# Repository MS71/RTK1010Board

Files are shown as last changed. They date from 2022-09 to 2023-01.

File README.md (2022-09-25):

# RTK1010Board
Arduino Compatible RTK1010 Board/PCB

! Design not finished yet !

Feature:

* Arduino compatibe form factor
* RTK1010 GPS receiver
* optional SMA connector for external antennas
* IPEX connector for onboard antennas
* optional LDO for LNA power supply
* optional ESP32-S2 for operating as base station
* optional power via USB
* optional backup battery
* optional BNO055 IMU

Use Cases:

A.) Minimum RTK-1010 receiver with arduino form factor. 
* just RTK-1010 to RX/TX arduino pin
* SMA or IPEX connected
* LNA power by rtk-1010
* optional backup bat for RTK-1010
* optional LNA LDO

B.) Minimum USB powered RTK base station with RTK-1010, ESP32-S2.  
* ESP32: RTK <=> TCP bridge
* powered by USB
* SMA or IPEX connected
* LNA power
* optional backup bat for RTK-1010
* optional LNA LDO

C.) Mowgli HEAD with RTK-1010, ESP32-S2 and BNO055 IMU (todo)
* ESP32: running microROS
* VCC, GND, UART interface to YF mainboard
* low power, sleep mode

[Build Manual](BuildManual.pdf)

[RTK 1010 datasheet](https://www.locosystech.com/Templates/att/RTK-1010_datasheet_v0.7.pdf)

[Schematic](RTK1010Board.pdf)


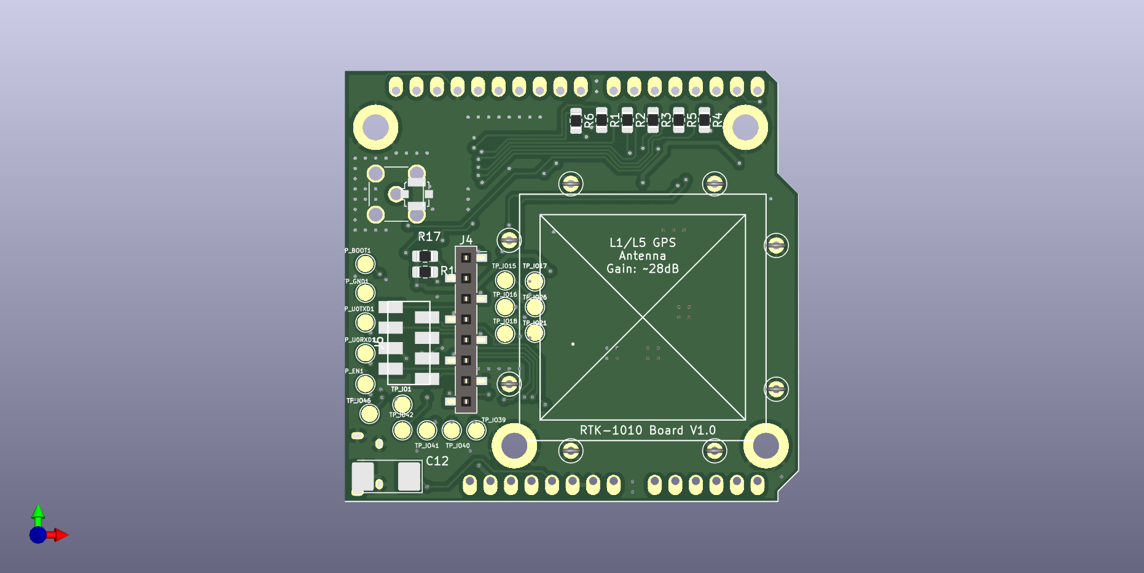
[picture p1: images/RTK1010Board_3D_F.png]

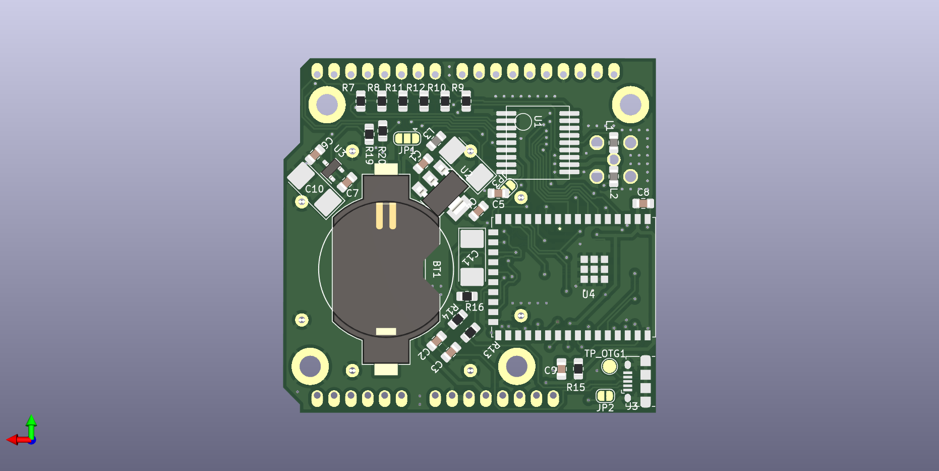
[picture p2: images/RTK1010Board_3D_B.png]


[iBOM](bom/ibom.html)

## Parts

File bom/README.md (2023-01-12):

# RTK1010-PCB-BOM

#### A) Minimum RTK-1010 receiver with arduino form factor

  - RTK-1010 <-> RX/TX arduino pins
  - SMA or IPEX connector
  - LNA power by RTK-1010
  - RTK-1010 backup battery
  - *(optional)* LNA LDO

#### B) Minimum RTK base station with RTK-1010 & ESP32-S2 powered by USB

  - ESP32: RTK <=> TCP bridge
  - powered by USB
  - SMA or IPEX connector
  - LNA power by RTK-1010
  - RTK-1010 backup battery
  - *(optional)* LNA LDO

#### C) Mowgli HEAD with RTK-1010, ESP32-S2 and BNO055 IMU *(TODO)*

  - ESP32: running microROS
  - VCC, GND, UART interface to YF mainboard
  - low power, sleep mode
  - SMA or IPEX connector
  - LNA power by RTK-1010
  - RTK-1010 backup battery
  - *(optional)* LNA LDO

## BOM-Tables

#### A) Minimum RTK-1010 receiver with arduino form factor

| Amount | Placement | Description | Reichelt Part# | Mouser Part# |
| :----: | :---: | :---: | :---: | :---: |
| 1 | U1 | RTK-1010 | - | - |
| 1 | C5 | 0805 capacitor 100nF | [KEM X7R0805 100N](https://reichelt.com/multi-layer-ceramic-capacitor-100nf-50v-125-c-kem-x7r0805-100n-p207073.html) | |
| 2 | C11,C13 | tantalum 100µF/10V | [T491C 100U 10](https://reichelt.com/smd-tantalum-100-f-10v-125-c-t491c-100u-10-p206478.html) | |
| 5 | C4,C5,C7,C8,C9 | 100nF/50V | [KEM Z5U0805 100N](https://www.reichelt.com/de/en/multi-layer-ceramic-capacitor-100nf-50v-85-c-kem-z5u0805-100n-p207084.html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) | |
| 2 | R7, R8 | 0805 resistor 100Ω | [SMD-0805 100](https://reichelt.com/smd-chip-resistor-type-0805-100-ohm-smd-0805-100-p32874.html) | |
| 1 | R15 | 0805 resistor 10kΩ | [SMD-0805 10,0K](https://reichelt.com/smd-chip-resistor-type-0805-10-k-ohm-smd-0805-10-0k-p32898.html) | |
| 2 | L1,L3 | 0804 Inductor 39nH | [L-0805AS 39N](https://www.reichelt.de/de/de/smd-induktivitaet-0805-keramik-39-nh-l-0805as-39n-p255488.html) | |
| 1 | J2 | | - | [73412-0110](https://mouser.com/ProductDetail/Molex/73412-0110?qs=NlNVDDZd7xQHV8e0ilpSdQ%3D%3D) |
| 1 | L1/L5 GPS | Linx active GPS antenna | - | [ANT-GNCP-C25L15100](https://mouser.com/ProductDetail/Linx-Technologies/ANT-GNCP-C25L15100?qs=7D1LtPJG0i2oOR5Ka99M8Q%3D%3D) |
| 1 | BT1 | CR2032 holder | [KEYSTONE 1058](https://reichelt.com/button-cell-holder-for-1x-20mm-keystone-1058-p213351.html) | |
| 1 | (BT1) | CR2032 | [CR2032](https://reichelt.com/lithium-button-cell-battery-3-volt-210-mah-20-0x3-2-mm-cr-2032-p26550.html) |  |

---

#### B) Minimum RTK base station with RTK-1010 & ESP32-S2 powered by USB

| Amount | Placement | Description | Reichelt Part# | Mouser Part# |
| :----: | :---: | :---: | :---: | :---: |
| 1 | U1 | RTK-1010 | - | - |
| 1 | U2 | 3.3V LDO | [NCP 1117 ST33T3G](https://www.reichelt.de/ldo-regler-fest-3-3-v-sot-223-ncp-1117-st33t3g-p188925.html?search=NCP1117) | - |
| 1 | C5 | 0805 capacitor 100nF | [KEM X7R0805 100N](https://reichelt.com/multi-layer-ceramic-capacitor-100nf-50v-125-c-kem-x7r0805-100n-p207073.html) | |
| 3 | C11,C12,C13 | tantalum 100µF/10V | [T491C 100U 10](https://reichelt.com/smd-tantalum-100-f-10v-125-c-t491c-100u-10-p206478.html) | |
| 5 | C4,C5,C7,C8,C9 | 100nF/50V | [KEM Z5U0805 100N](https://www.reichelt.com/de/en/multi-layer-ceramic-capacitor-100nf-50v-85-c-kem-z5u0805-100n-p207084.html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) | |
| 4 | R4,R5,R13,R14  | 0805 resistor 100Ω | [SMD-0805 100](https://reichelt.com/smd-chip-resistor-type-0805-100-ohm-smd-0805-100-p32874.html) | |
| 2 | R15,R16 | 0805 resistor 10kΩ | [SMD-0805 10,0K](https://reichelt.com/smd-chip-resistor-type-0805-10-k-ohm-smd-0805-10-0k-p32898.html) | |
| 2 | L1,L3 | 0804 Inductor 39nH | [L-0805AS 39N](https://www.reichelt.de/de/de/smd-induktivitaet-0805-keramik-39-nh-l-0805as-39n-p255488.html) | |
| 1 | J2 | | - | [73412-0110](https://mouser.com/ProductDetail/Molex/73412-0110?qs=NlNVDDZd7xQHV8e0ilpSdQ%3D%3D) |
| 1 | L1/L5 GPS | Linx active GPS antenna | - | [ANT-GNCP-C25L15100](https://mouser.com/ProductDetail/Linx-Technologies/ANT-GNCP-C25L15100?qs=7D1LtPJG0i2oOR5Ka99M8Q%3D%3D) |
| 1 | BT1 | CR2032 holder | [KEYSTONE 1058](https://reichelt.com/button-cell-holder-for-1x-20mm-keystone-1058-p213351.html) | |
| 1 | (BT1) | CR2032 | [CR2032](https://reichelt.com/lithium-button-cell-battery-3-volt-210-mah-20-0x3-2-mm-cr-2032-p26550.html) |  |
| 2 | C2, C3 | 0805 capacitor 100pF | [KEM C0G0805 100P](https://reichelt.com/multi-layer-ceramic-capacitor-100pf-50v-125-c-kem-c0g0805-100p-p207035.html) | |
| 1 | J3 | USB socket | - | [649-10118194-0001LF](https://eu.mouser.com/ProductDetail/Amphenol-FCI/10118194-0001LF?qs=Ywefl8B65e4FIdY8OWfRQA%3D%3D) |
| 1 | U4 | ESP32-S2 | [ESP32S2WROVERI4 (sma antenna)](https://reichelt.com/wifi-modul-802-11-bt-2-4-2-5ghz-150mb-s-esp32s2wroveri4-p311738.html)<br>***or***<br>[ESP32-S2-WROVER (pcb antenna)](https://reichelt.com/wifi-smd-module-esp32-s2-4-mb-spi-2mb-psram-18x31x3-3-mm-esp32-s2-wrover-p300188.html) | [ESP32-S2-WROVER-I (sma antenna)](https://mouser.com/ProductDetail/Espressif-Systems/ESP32-S2-WROVER-IM22S2H3216UH3Q0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)<br>***or***<br>[ESP32-S2-WROVER (pcb antenna)](https://mouser.com/ProductDetail/Espressif-Systems/ESP32-S2-WROVERM22S2H3216PH3Q0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) |
| 1 | Mode Header | Header | [Header](https://www.reichelt.de/stiftleisten-2-54-mm-1x02-gerade-mpe-087-1-002-p119879.html?&trstct=pol_0&nbc=1)| - |
| 1 | Mode Jumper | Jumper | [Jumper](https://www.reichelt.de/kurzschlussbruecke-rot-mit-grifflasche-jumper-2-54gl-rt-p9018.html?&trstct=pol_0&nbc=1)| - |

---

#### C) Mowgli HEAD with RTK-1010, ESP32-S2 and BNO055 IMU *(TODO)*

| Amount | Placement | Description | Reichelt Part# | Mouser Part# |
| :----: | :---: | :---: | :---: | :---: |
| 1 | U1 | RTK-1010 | - | - |
| 1 | C5 | 0805 capacitor 100nF | [KEM X7R0805 100N](https://reichelt.com/multi-layer-ceramic-capacitor-100nf-50v-125-c-kem-x7r0805-100n-p207073.html) | |
| 3 | C11,C12,C13 | tantalum 100µF/10V | [T491C 100U 10](https://reichelt.com/smd-tantalum-100-f-10v-125-c-t491c-100u-10-p206478.html) | |
| 5 | C4,C5,C7,C8,C9 | 100nF/50V | [KEM Z5U0805 100N](https://www.reichelt.com/de/en/multi-layer-ceramic-capacitor-100nf-50v-85-c-kem-z5u0805-100n-p207084.html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) | |
| 4 | R4,R5,R13,R14  | 0805 resistor 100Ω | [SMD-0805 100](https://reichelt.com/smd-chip-resistor-type-0805-100-ohm-smd-0805-100-p32874.html) | |
| 4 | R15,R16,R17,R18| 0805 resistor 10kΩ | [SMD-0805 10,0K](https://reichelt.com/smd-chip-resistor-type-0805-10-k-ohm-smd-0805-10-0k-p32898.html) | |
| 2 | L1,L3 | 0804 Inductor 39nH | [L-0805AS 39N](https://www.reichelt.de/de/de/smd-induktivitaet-0805-keramik-39-nh-l-0805as-39n-p255488.html) | |
| 1 | J2 | | - | [73412-0110](https://mouser.com/ProductDetail/Molex/73412-0110?qs=NlNVDDZd7xQHV8e0ilpSdQ%3D%3D) |
| 1 | L1/L5 GPS | Linx active GPS antenna | - | [ANT-GNCP-C25L15100](https://mouser.com/ProductDetail/Linx-Technologies/ANT-GNCP-C25L15100?qs=7D1LtPJG0i2oOR5Ka99M8Q%3D%3D) |
| 1 | BT1 | CR2032 holder | [KEYSTONE 1058](https://reichelt.com/button-cell-holder-for-1x-20mm-keystone-1058-p213351.html) | |
| 1 | (BT1) | CR2032 | [CR2032](https://reichelt.com/lithium-button-cell-battery-3-volt-210-mah-20-0x3-2-mm-cr-2032-p26550.html) |  |
| 2 | C2, C3 | 0805 capacitor 100pF | [KEM C0G0805 100P](https://reichelt.com/multi-layer-ceramic-capacitor-100pf-50v-125-c-kem-c0g0805-100p-p207035.html) | |
| 1 | U4 | ESP32-S2 | [ESP32S2WROVERI4 (sma antenna)](https://reichelt.com/wifi-modul-802-11-bt-2-4-2-5ghz-150mb-s-esp32s2wroveri4-p311738.html)<br>***or***<br>[ESP32-S2-WROVER (pcb antenna)](https://reichelt.com/wifi-smd-module-esp32-s2-4-mb-spi-2mb-psram-18x31x3-3-mm-esp32-s2-wrover-p300188.html) | [ESP32-S2-WROVER-I (sma antenna)](https://mouser.com/ProductDetail/Espressif-Systems/ESP32-S2-WROVER-IM22S2H3216UH3Q0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)<br>***or***<br>[ESP32-S2-WROVER (pcb antenna)](https://mouser.com/ProductDetail/Espressif-Systems/ESP32-S2-WROVERM22S2H3216PH3Q0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) |
| 1 | J5 | Micro Match SMD | [MPE 374-2-008](https://www.reichelt.de/buchsenleisten-micro-match-smd-1-27-mm-2x04-l-mpe-374-2-008-p120017.html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) | |
| 1 | J4 | BNO055 Connector | [2,54 mm, 1X08](https://www.reichelt.de/buchsenleisten-2-54-mm-1x08-gerade-mpe-094-1-008-p119917.html?&trstct=pol_0&nbc=1) | |
| 1 | Mode Header | Header | [Header](https://www.reichelt.de/stiftleisten-2-54-mm-1x02-gerade-mpe-087-1-002-p119879.html?&trstct=pol_0&nbc=1)| - |
| 1 | Mode Jumper | Jumper | [Jumper](https://www.reichelt.de/kurzschlussbruecke-rot-mit-grifflasche-jumper-2-54gl-rt-p9018.html?&trstct=pol_0&nbc=1)| - |

#### Option LNA LDO

| Amount | Placement | Description | Reichelt Part# | Mouser Part# |
| :----: | :---: | :---: | :---: | :---: |
| 1 | U3 | 3.3V LDO | [NCP 1117 ST33T3G](https://www.reichelt.de/ldo-regler-fest-3-3-v-sot-223-ncp-1117-st33t3g-p188925.html?search=NCP1117) | - |
| 1 | C6 | 100nF/50V | [KEM Z5U0805 100N](https://www.reichelt.com/de/en/multi-layer-ceramic-capacitor-100nf-50v-85-c-kem-z5u0805-100n-p207084.html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) | |

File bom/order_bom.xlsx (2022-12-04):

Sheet: Info
Variants: (https://github.com/MS71/RTK1010Board)see
A.) Minimum RTK-1010 receiver with arduino form factor.
just RTK-1010 to RX/TX arduino pin
SMA or IPEX connected
LNA power by rtk-1010
optional backup bat for RTK-1010
optional LNA LDO
B.) Minimum USB powered RTK base station with RTK-1010, ESP32-S2.
ESP32: RTK <=> TCP bridge
powered by USB
SMA or IPEX connected
LNA power
optional backup bat for RTK-1010
optional LNA LDO
C.) Mowgli HEAD with RTK-1010, ESP32-S2 and BNO055 IMU (todo)
ESP32: running microROS
VCC, GND, UART interface to YF mainboard
low power, sleep mode

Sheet: Variant A (Reichelt)
Amount | Part | Description | URL
1 | T491C 100U 10 | SMD-Tantal, 100µF, 10V, 125°C | https://www.reichelt.de/de/de/smd-tantal-100-f-10v-125-c-t491c-100u-10-p206478.html?search=T491C+100U+&r=1
2 | L-0805AS 39N | SMD-Induktivität, 0805, Keramik, 39 nH | https://www.reichelt.de/smd-induktivitaet-0805-keramik-39-nh-l-0805as-39n-p255488.html?trstct=pos_0&nbc=1
3 | KEM X7R0805 100N | Vielschicht-Kerko, 100nF, 50V, 125°C | https://www.reichelt.de/vielschicht-kerko-100nf-50v-125-c-kem-x7r0805-100n-p207073.html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
2 | RND 1550805 AZ | SMD-Widerstand, 0805, 100 Ohm, 125 mW, 5% | https://www.reichelt.de/smd-widerstand-0805-100-ohm-125-mw-5--rnd-1550805-az-p250243.html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
1 | KEYSTONE 1058 | Knopfzellenhalter für 1 Ø 20 mm | https://www.reichelt.de/knopfzellenhalter-fuer-1-20-mm-keystone-1058-p213351.html?search=keystone+1058
1 | CR 2032 | Lithium-Knopfzelle, 3 V, 210 mAh, 20,0x3,2 mm | https://www.reichelt.de/lithium-knopfzelle-3-v-210-mah-20-0x3-2-mm-cr-2032-p26550.html?trstct=pos_2&nbc=1

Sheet: Variant A (Mouser)
Amount | Part | Description | URL
1 | ANT-GNCP-C25L15100 | L1+L5 active Antenna | https://www.mouser.de/ProductDetail/Linx-Technologies/ANT-GNCP-C25L15100?qs=7D1LtPJG0i2oOR5Ka99M8Q%3D%3D

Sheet: Variant B (Reichelt)
Amount | Part | Description | URL
…
1 | ESP32S2WROVERI4 | WiFi-Modul 802.11/BT 2,4-2,5GHz 150Mb/s | https://www.reichelt.de/wifi-modul-802-11-bt-2-4-2-5ghz-150mb-s-esp32s2wroveri4-p311738.html?search=ESP32+S2+w

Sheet: Variant B (Mouser)
Amount | Part | Description | URL
1 | ANT-GNCP-C25L15100 | L1+L5 active Antenna | https://www.mouser.de/ProductDetail/Linx-Technologies/ANT-GNCP-C25L15100?qs=7D1LtPJG0i2oOR5Ka99M8Q%3D%3D
1 | 649-10118194-0001LF | USB Connector | https://eu.mouser.com/ProductDetail/Amphenol-FCI/10118194-0001LF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

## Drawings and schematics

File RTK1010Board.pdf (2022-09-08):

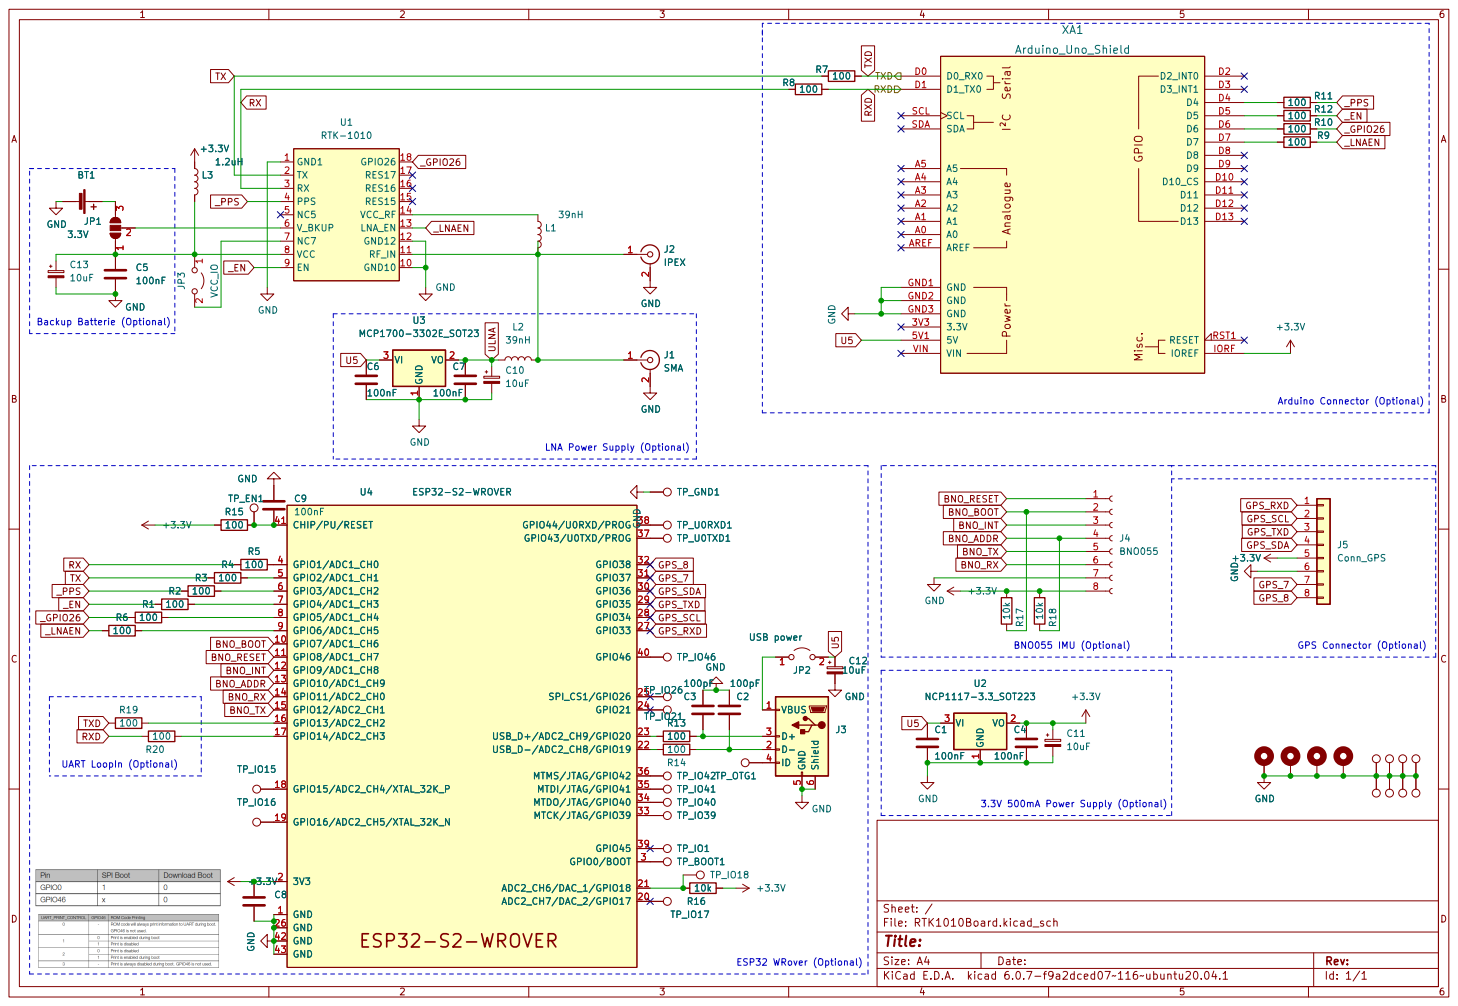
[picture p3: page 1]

BNO055 IMU (Optional)

GPS Connector (Optional)

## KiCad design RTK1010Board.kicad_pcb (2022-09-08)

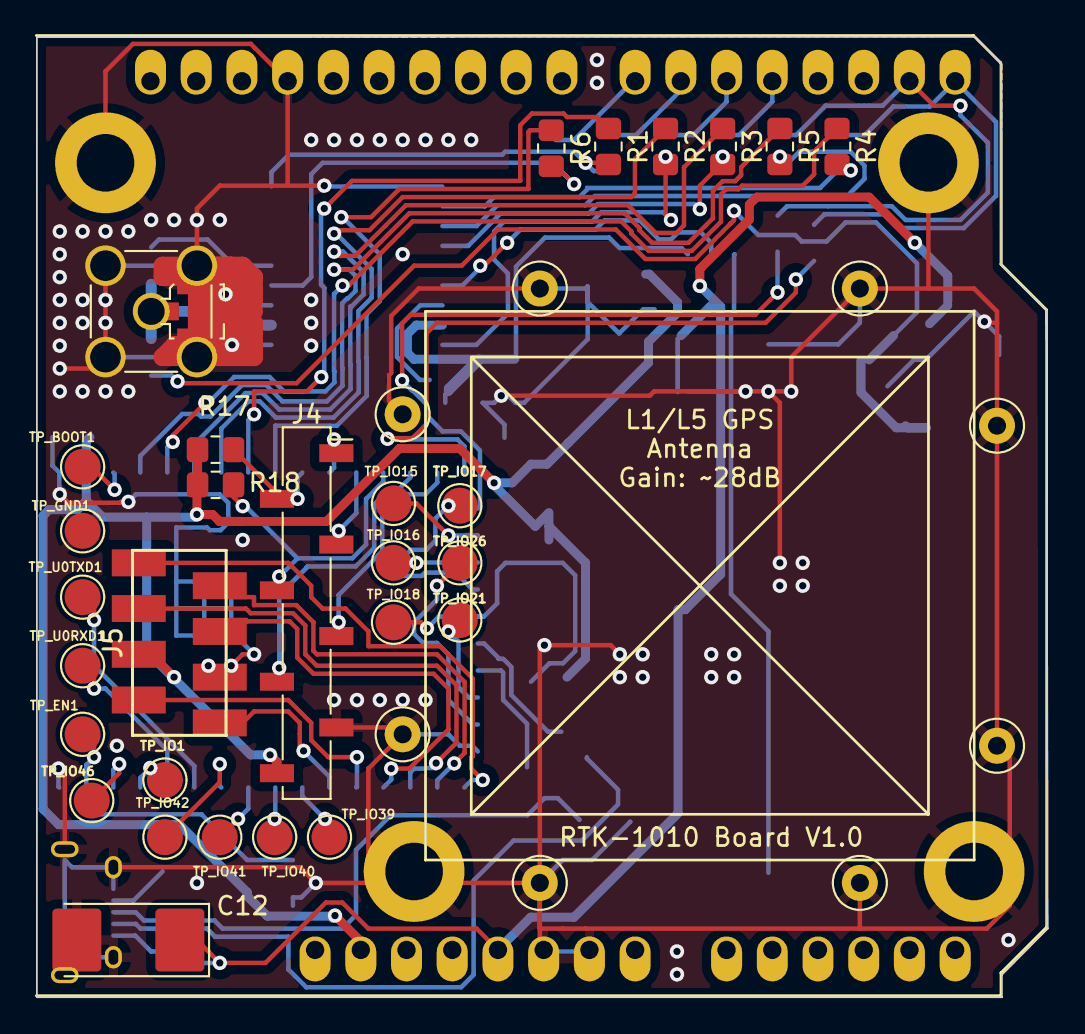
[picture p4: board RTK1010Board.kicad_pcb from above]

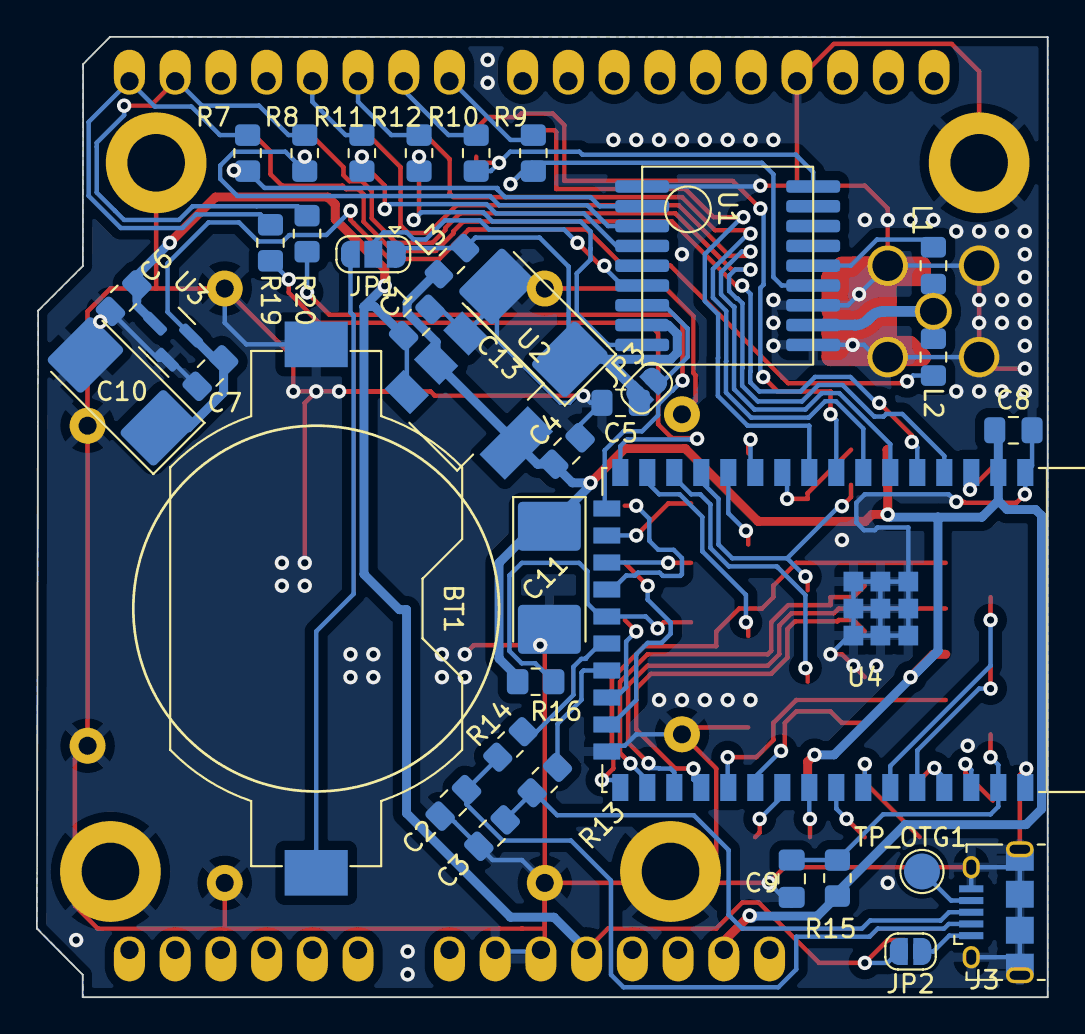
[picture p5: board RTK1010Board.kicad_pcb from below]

Board: 2 copper layers, 56.2 x 53.3 mm, 80 parts (37 on the bottom side), 60 nets.

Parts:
BT1: 3.3V; BatteryHolder_Keystone_1058_1x2032
C1, C4, C5, C6, C7, C8, C9: 100nF; C_0805_2012Metric_Pad1.18x1.45mm_HandSolder
C2, C3: 100pF; C_0805_2012Metric_Pad1.18x1.45mm_HandSolder
C10, C11, C12, C13: 10uF; CP_EIA-7132-20_AVX-U_Pad2.72x3.50mm_HandSolder
H1, H2, H3, H4: MountingHole_Pad; MountingHole_3.2mm_M3_DIN965_Pad
J1: SMA; SMA_Amphenol_132134-11_Vertical
J2: IPEX; U.FL_Molex_MCRF_73412-0110_Vertical
J3: USB_OTG; USB_Micro-B_Amphenol_10118194_Horizontal
J4: BNO055; PinSocket_1x08_P2.54mm_Vertical_SMD_Pin1Right
J5: Conn_GPS; CONN-TE-MICROMATCH-4X2-SMD
JP1: SolderJumper_3_Open; SolderJumper-3_P1.3mm_Open_RoundedPad1.0x1.5mm
JP2: USB power; SolderJumper-2_P1.3mm_Open_RoundedPad1.0x1.5mm
JP3: VCC_IO; SolderJumper-2_P1.3mm_Open_RoundedPad1.0x1.5mm
L1, L2: 39nH; L_0805_2012Metric_Pad1.15x1.40mm_HandSolder
L3: 1.2uH; L_0805_2012Metric_Pad1.15x1.40mm_HandSolder
R1, R2, R3, R4, R5, R6, R7, R8, R9, R10, R11, R12, R13, R14, R15, R19, R20: 100; R_0805_2012Metric_Pad1.20x1.40mm_HandSolder
R16, R17, R18: 10k; R_0805_2012Metric_Pad1.20x1.40mm_HandSolder
TP1, TP2, TP3, TP4, TP5, TP6, TP7, TP8: TestPoint; TestPoint_Loop_D2.50mm_Drill1.0mm
TP_BOOT1: TestPoint; TestPoint_Pad_D2.0mm
TP_EN1: TestPoint; TestPoint_Pad_D2.0mm
TP_GND1: TestPoint; TestPoint_Pad_D2.0mm
TP_IO1, TP_IO15, TP_IO16, TP_IO17, TP_IO18, TP_IO21, TP_IO26, TP_IO39, TP_IO40, TP_IO41, TP_IO42, TP_IO46: TestPoint; TestPoint_Pad_D2.0mm
TP_OTG1: TestPoint; TestPoint_Pad_D2.0mm
TP_U0RXD1, TP_U0TXD1: TestPoint; TestPoint_Pad_D2.0mm
U1: RTK-1010; rtk1010
U2: NCP1117-3.3_SOT223; SOT-223-3_TabPin2
U3: MCP1700-3302E_SOT23; SOT-23
U4: ESP32-S2-WROVER
XA1: Arduino_Uno_Shield

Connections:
+3V3: C4.1, C8.1, C11.1, J4.8, J5.5, L3.1, R15.2, R16.1, R17.1, R18.1, U2.2 (VO), U4.2 (3V3), XA1.IORF (IOREF)
BNO_ADDR: J4.4, R18.2, U4.13 (GPIO10/ADC1_CH9)
BNO_BOOT: J4.2, R17.2, U4.10 (GPIO7/ADC1_CH6)
BNO_INT: J4.3, U4.12 (GPIO9/ADC1_CH8)
BNO_RESET: J4.1, U4.11 (GPIO8/ADC1_CH7)
BNO_RX: J4.6, U4.14 (GPIO11/ADC2_CH0)
BNO_TX: J4.5, U4.15 (GPIO12/ADC2_CH1)
GND: BT1.2 (-), C1.2, C2.1, C3.1, C4.2, C5.2, C6.2, C7.2, C8.2, C9.1, C10.2, C11.2, C12.2, C13.2, H1.1, H2.1, H3.1, H4.1, J1.2 (Ext), J2.2 (Ext), J3.5 (GND), J3.6 (Shield), J4.7, J5.6, TP1.1, TP2.1, TP3.1, TP4.1, TP5.1, TP6.1, TP7.1, TP8.1, TP_GND1.1, U1.1 (GND1), U1.10 (GND10), U1.12 (GND12), U2.1 (GND), U3.1 (GND), U4.1 (GND), U4.26 (GND), U4.42 (GND), U4.43 (GND), XA1.GND1 (GND), XA1.GND2 (GND), XA1.GND3 (GND)
GPS_7: J5.7, U4.31 (GPIO37)
GPS_8: J5.8, U4.32 (GPIO38)
GPS_RXD: J5.1, U4.27 (GPIO33)
GPS_SCL: J5.2, U4.28 (GPIO34)
GPS_SDA: J5.4, U4.30 (GPIO36)
GPS_TXD: J5.3, U4.29 (GPIO35)
unnamed: BT1.1 (+), JP1.3 (B)
unnamed: C2.2, J3.2 (D-), R14.1
unnamed: C3.2, J3.3 (D+), R13.1
unnamed: C9.2, R15.1, TP_EN1.1, U4.41 (CHIP/PU/RESET)
unnamed: C5.1, C13.1, JP1.1 (A), JP3.1 (A), L3.2, U1.8 (VCC)
unnamed: J1.1 (In), J2.1 (In), L1.2, L2.2, U1.11 (RF_IN)
unnamed: J3.1 (VBUS), JP2.1 (A)
unnamed: J3.4 (ID), TP_OTG1.1
unnamed: JP1.2 (C), U1.6 (V_BKUP)
unnamed: JP3.2 (B), U1.7 (NC7)
unnamed: L1.1, U1.14 (VCC_RF)
unnamed: R1.1, U4.8 (GPIO5/ADC1_CH4)
unnamed: R2.1, U4.7 (GPIO4/ADC1_CH3)
unnamed: R3.1, U4.6 (GPIO3/ADC1_CH2)
unnamed: R4.1, U4.5 (GPIO2/ADC1_CH1)
unnamed: R5.1, U4.4 (GPIO1/ADC1_CH0)
unnamed: R6.1, U4.9 (GPIO6/ADC1_CH5)
unnamed: R9.2, XA1.D7
unnamed: R10.2, XA1.D6
unnamed: R11.1, XA1.D4
unnamed: R12.1, XA1.D5
unnamed: R13.2, U4.23 (USB_D+/ADC2_CH9/GPIO20)
unnamed: R14.2, U4.22 (USB_D-/ADC2_CH8/GPIO19)
unnamed: R16.2, TP_IO18.1, U4.21 (ADC2_CH6/DAC_1/GPIO18)
unnamed: R19.1, U4.16 (GPIO13/ADC2_CH2)
unnamed: R20.1, U4.17 (GPIO14/ADC2_CH3)
unnamed: TP_BOOT1.1, U4.3 (GPIO0/BOOT)
unnamed: TP_IO15.1, U4.18 (GPIO15/ADC2_CH4/XTAL_32K_P)
unnamed: TP_IO16.1, U4.19 (GPIO16/ADC2_CH5/XTAL_32K_N)
unnamed: TP_IO39.1, U4.33 (MTCK/JTAG/GPIO39)
unnamed: TP_IO40.1, U4.34 (MTDO/JTAG/GPIO40)
unnamed: TP_IO41.1, U4.35 (MTDI/JTAG/GPIO41)
unnamed: TP_IO42.1, U4.36 (MTMS/JTAG/GPIO42)
unnamed: TP_IO46.1, U4.40 (GPIO46)
unnamed: TP_U0RXD1.1, U4.38 (GPIO44/U0RXD/PROG)
unnamed: TP_U0TXD1.1, U4.37 (GPIO43/U0TXD/PROG)
RX: R5.2, R8.1, U1.3 (RX)
RXD: R8.2, R20.2, XA1.D1 (D1_TX0)
TX: R4.2, R7.2, U1.2 (TX)
TXD: R7.1, R19.2, XA1.D0 (D0_RX0)
U5: C1.1, C6.1, C12.1, JP2.2 (B), U2.3 (VI), U3.3 (VI), XA1.5V1 (5V)
ULNA: C7.1, C10.1, L2.1, U3.2 (VO)
_EN: R2.2, R12.2, U1.9 (EN)
_GPIO26: R1.2, R10.1, U1.18 (GPIO26)
_LNAEN: R6.2, R9.1, U1.13 (LNA_EN)
_PPS: R3.2, R11.2, U1.4 (PPS)

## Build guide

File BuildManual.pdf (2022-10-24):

# RTK1010Board Building Manual

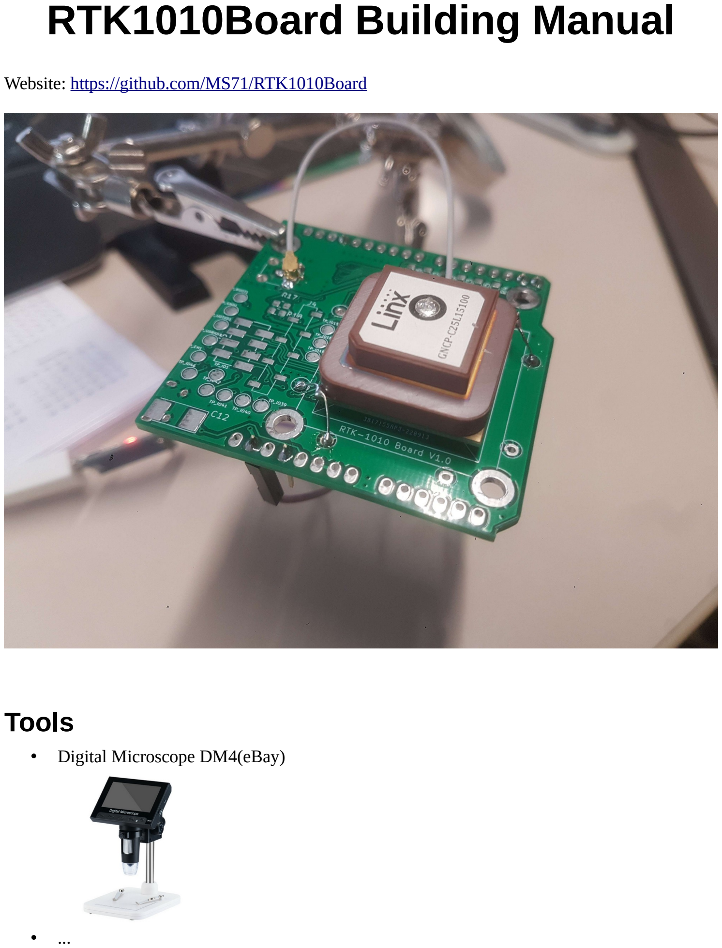
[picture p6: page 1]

Website: https://github.com/MS71/RTK1010Board

## Tools

- Digital Microscope DM4(eBay)

## Variant A) Minimum RTK-1010 receiver with arduino form factor

- just RTK-1010 to RX/TX arduino pin
- SMA or IPEX connected
- LNA power by rtk-1010
- My active GPS antenna. (Linx:NT-GNCP-C25L15100) (https://www.mouser.de/ProductDetail/Linx-Technologies/ANT-GNCP-C25L15100?qs=7D1LtPJG0i2oOR5Ka99M8Q%3D%3D)

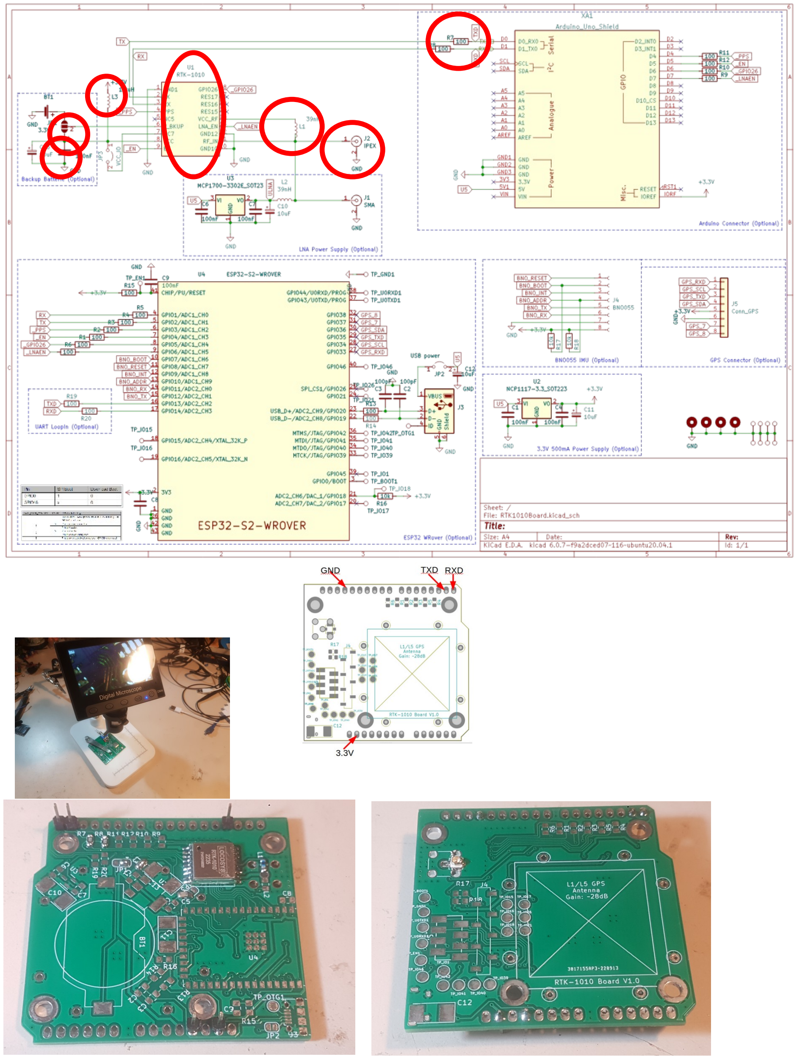
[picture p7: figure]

Reichelt:

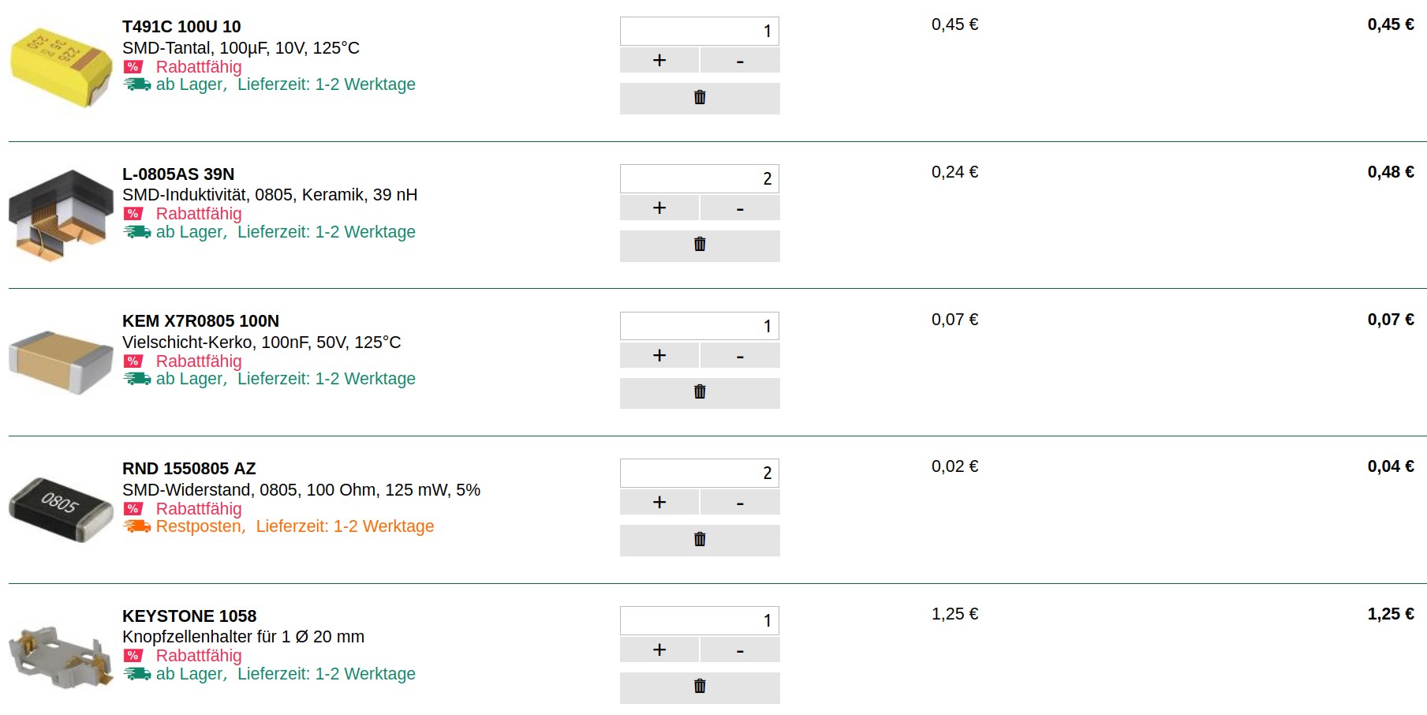
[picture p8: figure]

## U1 RTK-1010

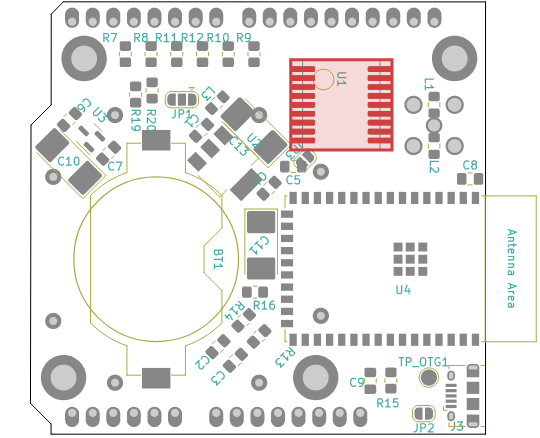
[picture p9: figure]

## L1 Coil 39nH

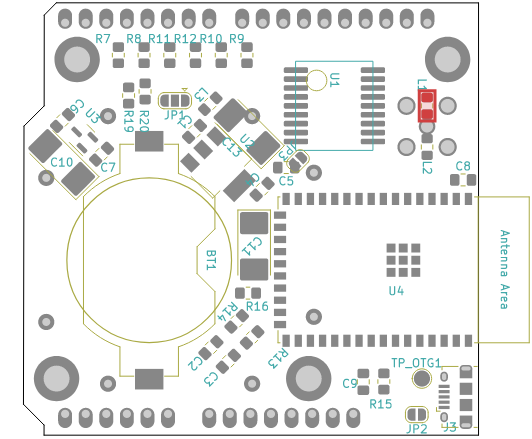
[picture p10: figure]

## C5 100nF

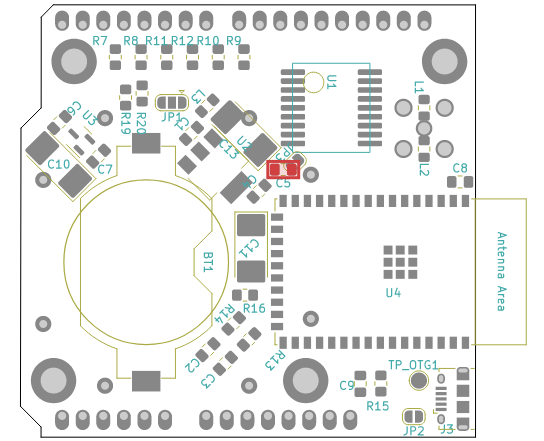
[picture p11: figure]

## J2 IPEX Connector

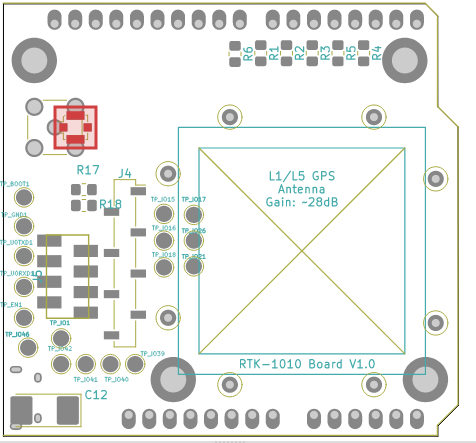
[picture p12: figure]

## L3 400mA Filter Coil

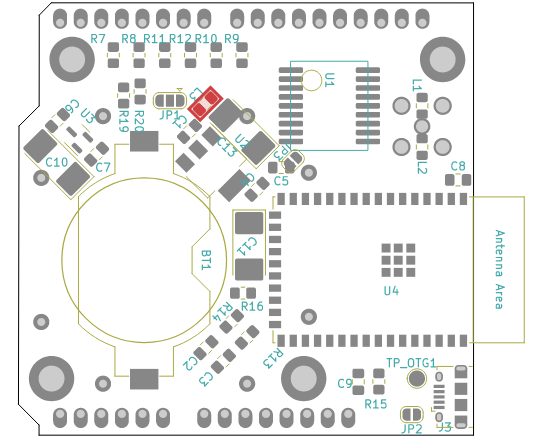
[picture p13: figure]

JP1 Connect V_BKUP with VCC

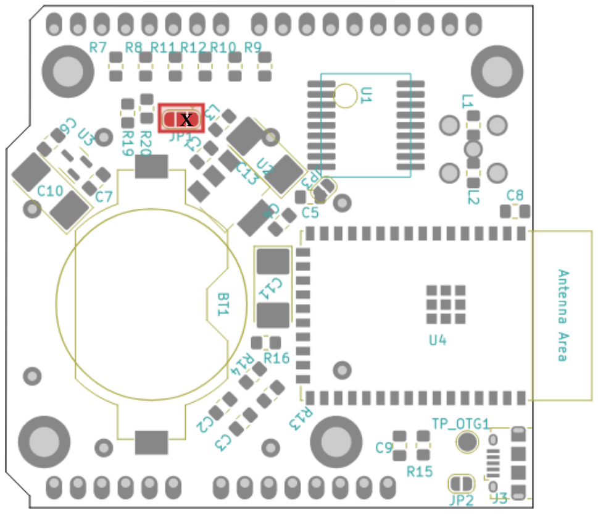
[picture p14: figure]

R6/R7 RX/TX Resistor

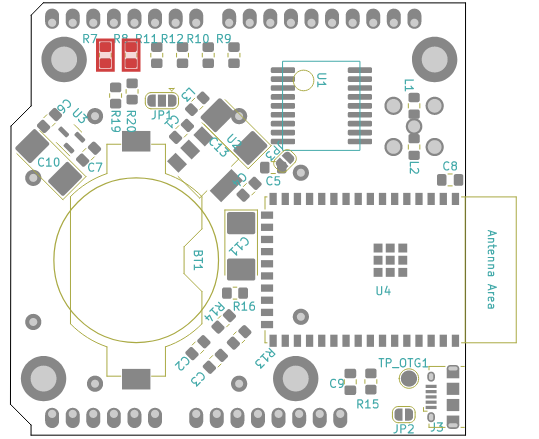
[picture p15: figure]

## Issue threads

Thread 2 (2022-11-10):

IOREF vs 3.3V supply

ClemensElflein, 2022-11-10:
I have noticed that the IOREF pin is used to power the RTK1010. This introduces currents on the 3.3V line if U2 is populated.

Instead of the IOREF pin, we should connect the 3.3V pin of the Arduino header and have a solder jumper to select if we want to draw power from the 3.3V pin or use U2 instead.

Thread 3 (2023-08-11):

Missing part numbers

itcnj, 2023-08-11:
I tried to follow the BOM to order parts through PCBWay but they could not find all the parts numbers to order and build them. Can anyone help?

https://docs.google.com/spreadsheets/d/1ini5PyBscC1Ly_wQgtdN2yeWO2_vyrWc/edit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

MS71, 2023-08-12:
The PCB was not made for automatic production.
I think, minor layout changes would be necessary.
And of course, adding some part information.

I think, it is not worth for doing this. But if you like,
you may complete/improve the design for supporting this.

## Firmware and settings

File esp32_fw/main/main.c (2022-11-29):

#include <string.h>
#include <stdlib.h>
#include "freertos/FreeRTOS.h"
#include "freertos/task.h"
#include "freertos/event_groups.h"
#include "esp_wifi.h"
#include "esp_wnm.h"
#include "esp_rrm.h"
#include "esp_mbo.h"
#include "esp_event.h"
#include "esp_log.h"
#include "esp_system.h"
#include "nvs_flash.h"
#include "esp_netif.h"
#include "tinyusb.h"
#include "tusb_cdc_acm.h"
#include "tusb_console.h"
//#include "gps.h"

static const char *TAG = "main";

void initialise_wifi();
void gps_init();

uint8_t powerstate()
{
    return 1;
}

void app_main(void)
{
    ESP_ERROR_CHECK(nvs_flash_init());

    tinyusb_config_t tusb_cfg = { 0 }; // the configuration uses default values
    ESP_ERROR_CHECK(tinyusb_driver_install(&tusb_cfg));

    tinyusb_config_cdcacm_t amc_cfg = { 0 }; // the configuration uses default values
    ESP_ERROR_CHECK(tusb_cdc_acm_init(&amc_cfg));

    esp_tusb_init_console(TINYUSB_CDC_ACM_0); // log to usb

    usleep(1000000);

    initialise_wifi();

    //usleep(10000000);

    gps_init();
    
    while(1)
    {
        //ESP_LOGI(TAG, "...");
        usleep(1000000);
    }
}

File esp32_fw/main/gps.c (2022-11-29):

#include "sdkconfig.h"

#define LOG_LOCAL_LEVEL ESP_LOG_VERBOSE

//#include <exception>
#include <math.h>
#include <stdio.h>
#include <stdlib.h>
#include <string.h>
#include <sys/time.h>

//#include "../components/http_server/my_http_server.h"
#include "esp_ota_ops.h"
#include "freertos/FreeRTOS.h"
#include "freertos/event_groups.h"
#include "freertos/semphr.h"
#include "freertos/task.h"

#include "driver/uart.h"
#include "esp_err.h"
#include "esp_event_loop.h"
#include "esp_log.h"
#include "esp_vfs.h"
#include "esp_vfs_dev.h"
#include "nvs_flash.h"

#include "ntrip.h"
#include <esp_http_client.h>

#include "lwip/err.h"
#include "lwip/sockets.h"
#include "lwip/sys.h"
#include <lwip/netdb.h>

#include "gpgga.h"
#include "gps.h"
#include "nmea.h"
#include "parser.h"

static const char* TAG = "gps";

extern EventGroupHandle_t wifi_event_group;
#define CONNECTED_BIT BIT0;

uint8_t powerstate();

#define PORT 20000

#define KEEPALIVE_IDLE 5
#define KEEPALIVE_INTERVAL 5
#define KEEPALIVE_COUNT 3

#define GPS_UART1_TXD 1
#define GPS_UART1_RXD 2
#undef GPS_UART1_INV

#ifdef RTK1010_NODE_ROVER_NTRIP_CLIENT
#define ENABLE_NTRIP_CLIENT
#endif

uint8_t gps_uart_ready = 0;
uint8_t gps_sapos_ready = 0;

#define RXBUF_SIZE 1024
uint8_t gps_rx_buffer[RXBUF_SIZE + 2];

static void gps_uart_handle();

struct
{
    struct
    {
        nmea_gpgga_s gga;
    } uart;
#ifdef ENABLE_NTRIP_CLIENT    
    struct
    {
        uint8_t needed;
        uint8_t reconnect;
        char host[48];
        uint16_t port;
        char username[32];
        char password[32];
        char mountpoint[32];
        int64_t reconnect_timeout;
        esp_http_client_handle_t http;
        int64_t gga_send_timeout;
        int64_t gga_print_timeout;
        int64_t ntrip_data_timeout;
        char gga_line[256];
        uint ntrip_rx_bytes;
    } ntrip;
#endif
    struct
    {
        int listen_sock;
        int client_sock;
    } tcpserv;
} gps_md = {};

static void gps_tcpserv_handle();
static void gps_uart_handle();

#ifdef ENABLE_NTRIP_CLIENT    
/**
 * @brief
 * @param evt
 * @return
 */
esp_err_t gps_ntrip_ev(esp_http_client_event_t* evt)
{
    switch(evt->event_id)
    {
    case HTTP_EVENT_ERROR:
        ESP_LOGI(TAG, "ntrip_ev() HTTP_EVENT_ERROR");
        break;
    case HTTP_EVENT_ON_CONNECTED:
        ESP_LOGI(TAG, "ntrip_ev() HTTP_EVENT_ON_CONNECTED");
        break;
    case HTTP_EVENT_HEADER_SENT:
        ESP_LOGI(TAG, "ntrip_ev() HTTP_EVENT_HEADER_SENT");
        break;
    case HTTP_EVENT_ON_HEADER:
        ESP_LOGI(TAG, "ntrip_ev() HTTP_EVENT_ON_HEADER");
        ESP_LOGI(TAG, "%.*s", evt->data_len, (char*)evt->data);
        break;
    case HTTP_EVENT_ON_DATA:
        // ESP_LOGV(TAG, "ntrip_ev() HTTP_EVENT_ON_DATA, len=%d", evt->data_len);
        gps_md.ntrip.ntrip_rx_bytes += evt->data_len;
        gps_md.ntrip.ntrip_data_timeout = esp_timer_get_time() + 30000000;
#if 0        
        if(!esp_http_client_is_chunked_response(evt->client))
        {
            ESP_LOGI(TAG, "%.*s", evt->data_len, (char*)evt->data);
        }
#endif
#if 0
        {
            ESP_LOGW(TAG, "ntrip_ev() HTTP_EVENT_ON_DATA, len=%d", evt->data_len);
        }
#endif
        if(uart_is_driver_installed(UART_NUM_1))
        {
            uart_write_bytes(UART_NUM_1, (const char*)evt->data, evt->data_len);
        }
        break;
    case HTTP_EVENT_ON_FINISH:
        ESP_LOGI(TAG, "ntrip_ev() HTTP_EVENT_ON_FINISH");
        break;
    case HTTP_EVENT_DISCONNECTED:
        ESP_LOGI(TAG, "ntrip_ev() HTTP_EVENT_DISCONNECTED");
        break;
    }
    return ESP_OK;
}

/**
 * @brief
 * @param pvParameters
 */
static void ntrip_task(void* pvParameters)
{
    (void)pvParameters;
    ESP_LOGI(TAG, "ntrip_task()  ...");

    while(true)
    {
        int ntrip_delay = 3000;

        EventBits_t ev = xEventGroupWaitBits(wifi_event_group, CONNECTED_BIT, false, true, 1 / portTICK_PERIOD_MS);
        if(ev != CONNECTED_BIT)
        {
            vTaskDelay(ntrip_delay / portTICK_PERIOD_MS);
            ESP_LOGI(TAG, "ntrip_task delay #1, retry");
            continue;
        }

        if(gps_md.ntrip.needed == 0)
        {
            vTaskDelay(ntrip_delay / portTICK_PERIOD_MS);
            ESP_LOGI(TAG, "ntrip_task delay #2, retry");
            continue;
        }

        gps_md.ntrip.gga_line[0] = 0;
        gps_md.ntrip.reconnect = 0;

        while(gps_md.ntrip.needed != 0)
        {
            if(gps_md.ntrip.reconnect_timeout > esp_timer_get_time())
            {
                vTaskDelay(ntrip_delay / portTICK_PERIOD_MS);
                ESP_LOGI(TAG, "ntrip_task delay #3, retry");
                continue;
            }

            ESP_LOGI(TAG, "ntrip_task starting ...");

            // Configure host URL
            esp_http_client_config_t config = {
                .host = gps_md.ntrip.host,
                .port = gps_md.ntrip.port,
                .method = HTTP_METHOD_GET,
            };
            config.path = (const char*)gps_md.ntrip.mountpoint;
            config.auth_type = HTTP_AUTH_TYPE_BASIC;
            config.username = (const char*)gps_md.ntrip.username;
            config.password = (const char*)gps_md.ntrip.password;
            config.event_handler = gps_ntrip_ev;

            ESP_LOGE(TAG, "ntrip_task() connect to %s:%d %s %s %s ...",config.host,config.port,config.username,config.password,config.path);

            // Initialize client
            gps_md.ntrip.http = esp_http_client_init(&config);
            esp_http_client_set_header(gps_md.ntrip.http, "Ntrip-Version", "Ntrip/2.0");
            esp_http_client_set_header(gps_md.ntrip.http, "User-Agent", "NTRIP " NTRIP_CLIENT_NAME "/2.0");
            esp_http_client_set_header(gps_md.ntrip.http, "Connection", "close");

            esp_err_t err = esp_http_client_open(gps_md.ntrip.http, 0);
            if(err != ESP_OK)
            {
                ESP_LOGE(TAG, "ntrip_task() Could not open HTTP connection: %d %s", err, esp_err_to_name(err));
                gps_md.ntrip.reconnect = 1;
                break;
            }

            int content_length = esp_http_client_fetch_headers(gps_md.ntrip.http);
            if(content_length < 0)
            {
                ESP_LOGE(TAG, "ntrip_task() Could not connect to caster: %d %s", errno, strerror(errno));
                gps_md.ntrip.reconnect = 1;
                break;
            }

            int status_code = esp_http_client_get_status_code(gps_md.ntrip.http);
            if(status_code != 200)
            {
                ESP_LOGE(TAG, "ntrip_task() Could not access mountpoint: %d", status_code);
                gps_md.ntrip.reconnect = 1;
                break;
            }
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

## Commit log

2022-08-08 first version
    [RTK1010Board.kicad_pcb, RTK1010Board.kicad_sch]
2022-08-08 schematic image added
    [RTK1010Board.kicad_pcb]
2022-08-08 gerber files added
    [RTK1010Board.kicad_pcb]
2022-08-08 ESP32-S2 mini replaced by WROVER module
    [RTK1010Board.kicad_pcb, RTK1010Board.kicad_sch]
2022-08-08 gerber files created
    [RTK1010Board.kicad_pcb]
2022-08-08 some more small changes
    [RTK1010Board.kicad_pcb, RTK1010Board.kicad_sch]
2022-08-14 bno055 added
    [RTK1010Board.kicad_pcb, RTK1010Board.kicad_sch]
2022-08-17 UART LoopIn option added USB connected to USB pins
    [RTK1010Board.kicad_pcb, RTK1010Board.kicad_sch]
2022-08-17 boot image added
    [RTK1010Board.kicad_sch]
2022-08-19 some optimiziations implemented
    [RTK1010Board.kicad_pcb, RTK1010Board.kicad_sch]
2022-08-21 RTK1010 VCC LP filter added
    [RTK1010Board.kicad_pcb, RTK1010Board.kicad_sch]
2022-08-25 Jefs comments implemented
    [RTK1010Board.kicad_pcb, RTK1010Board.kicad_sch]
2022-08-25 some vias added
    [RTK1010Board.kicad_pcb]
2022-08-25 some minor changes
    [RTK1010Board.kicad_pcb]
2022-08-27 LDO replaced by 500ma type
    [RTK1010Board.kicad_pcb, RTK1010Board.kicad_sch]
2022-09-03 support for teseo-liv3fl added
    [RTK1010Board.kicad_pcb, RTK1010Board.kicad_sch]
2022-09-06 ibom added
    [RTK1010Board.kicad_pcb, RTK1010Board.kicad_sch]
2022-09-06 ibom improved
    [RTK1010Board.kicad_sch]
2022-09-06 ibom updated
    [RTK1010Board.kicad_pcb, RTK1010Board.kicad_sch]
2022-10-24 esp32_fw added
    [RTK1010Board.kicad_sch]
2023-01-12 bom added
    [RTK1010Board.kicad_sch]
